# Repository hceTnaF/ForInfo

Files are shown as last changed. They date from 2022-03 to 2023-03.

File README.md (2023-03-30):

# ForInfo-V1.0 可信赖的桌面助理

## :one: 使用前准备

### 1.  硬件BOM已同步至ForInfo/1.hardware/Bom.list；
### 2.  硬件Gerber文件已同步至ForInfo/1.hardware/gerber,可直接打样（板厚1.2mm）；
### 3.  程序bin文件已同步至ForInfo/2.firmware；
### 4.  3D打印文件已同步至ForInfo/3.STL；
### 5.  ESP32程序下载工具已同步至ForInfo/5.tools；
### 6.  天气城市代码获取流程：
硬件初始化或重置后的流程中，需要在web界面填写天气城市代码以获取对应地区的天气信息，
为方便查询，可登录 [hcetnaf.com](https://www.hcetnaf.com/) 快速获取，流程如下：

#### **1）登录网站后，等待数据加载完毕；** 
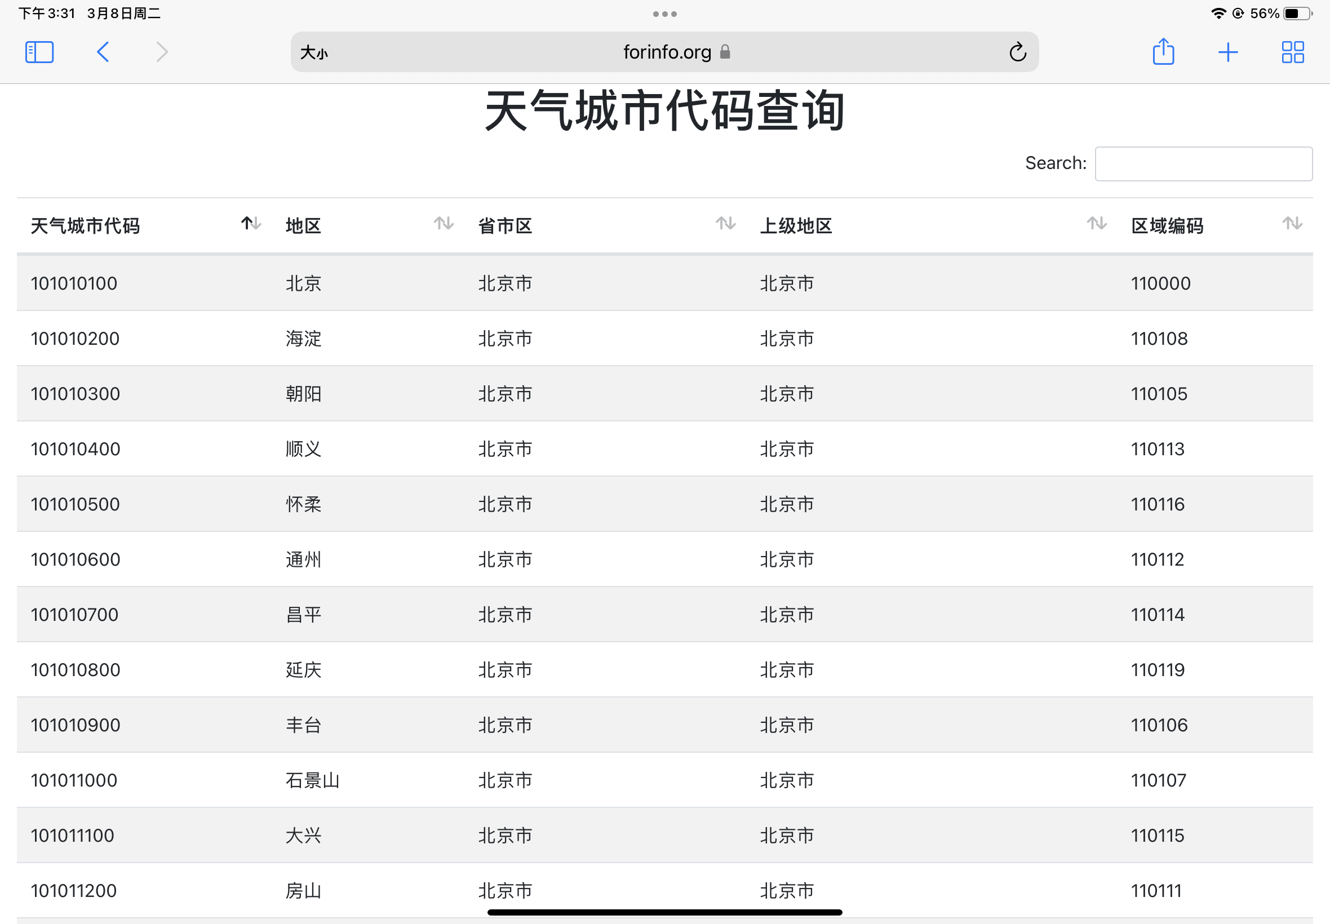
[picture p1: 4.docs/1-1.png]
数据加载

#### **2）在右上角搜索框内，可输入相应地名或区域编码完成搜索；** 
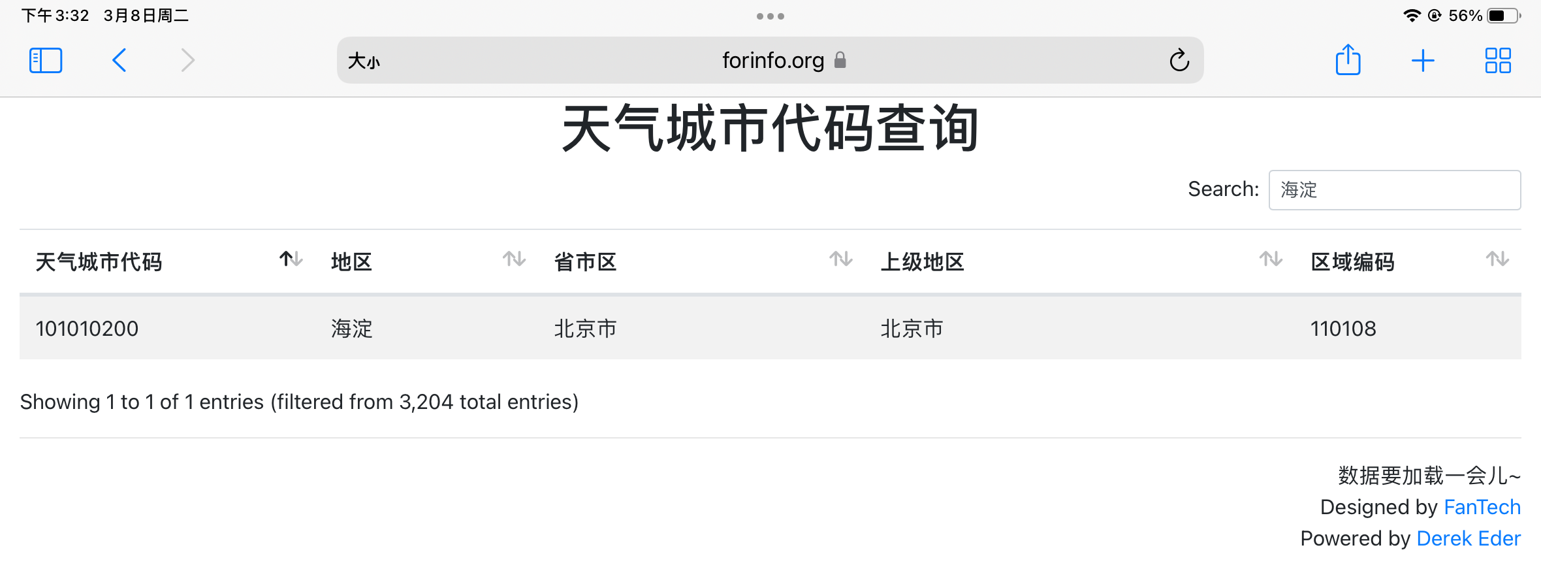
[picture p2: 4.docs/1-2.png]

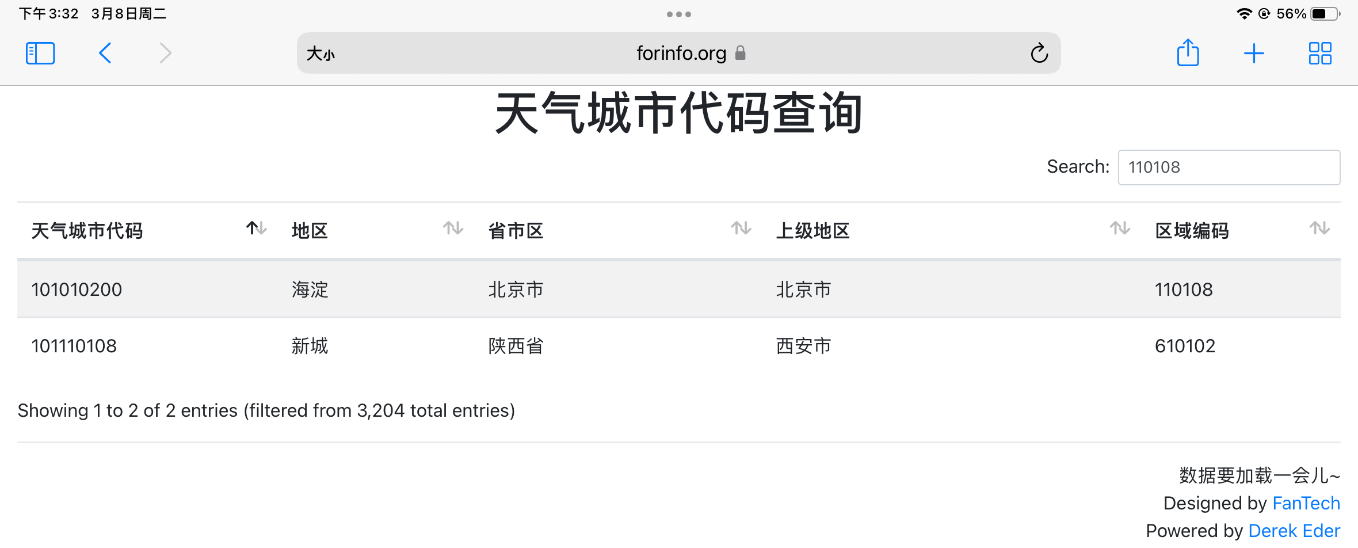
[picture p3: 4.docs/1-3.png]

#### **3）获得对应地区的天气城市代码并记录，如北京-海淀地区的天气城市代码为：101010200.** 

## :two: 下载方法
程序烧录过程，可使用 **5.tools** 中的ESP下载工具烧录，可较为方便的完成程序烧录以及后期版本升级等。双击" **flash_download_tools_v3.6.5.exe** "，选择" **ESP32 DownloadTool** ",并按照如下图所示加载4种bin文件，并正确填写后方对应的地址以及勾选下方对应的选项，如下图所示：

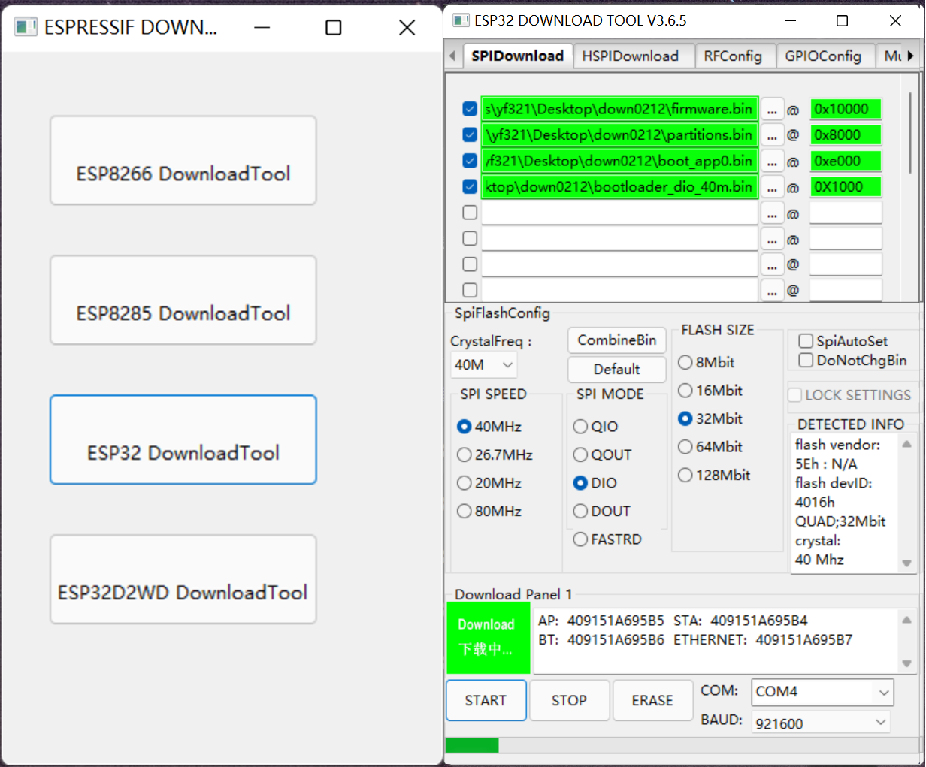
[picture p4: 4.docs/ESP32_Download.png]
下载配置


配置好相应选项后，点击 **START** 按钮方可进行下载（后续如遇异常问题，可先点击 **ERASE** 擦除后再点击 **START**）

## :three: 功能介绍

### 1.  配网过程
在系统初始化、重置系统，以及更换路由器或装置被拿到其它地方后，需要重新配置WiFi、天气城市代码、天气刷新时间、自定义字符等信息，此时装置液晶屏幕对应状态如下：

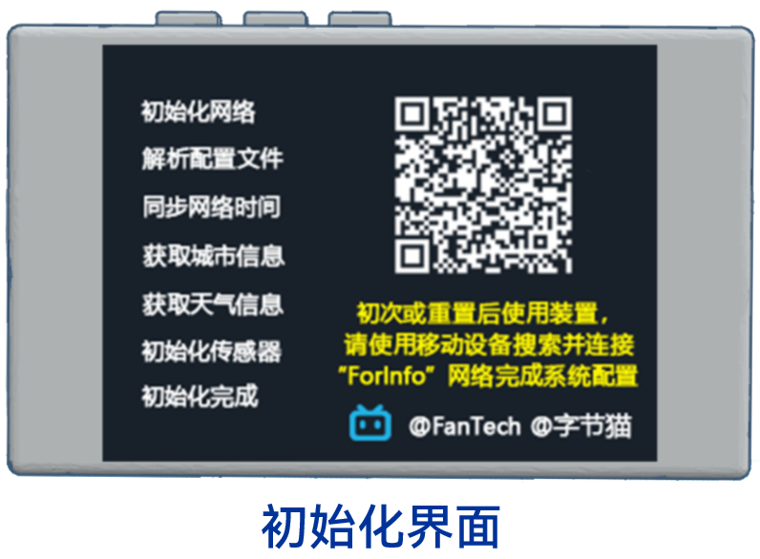
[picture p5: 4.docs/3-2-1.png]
初始化界面


其中，当出现上述几种情况时，界面会处于 **初始化界面** ，屏幕显示装置介绍二维码，可通过扫码了解装置介绍，以及获取 **天气城市代码** 等必要信息；了解了装置设置流程后，可使用移动设备搜索装置WiFi网络（ForInfo），并按照下图配置正确的信息：

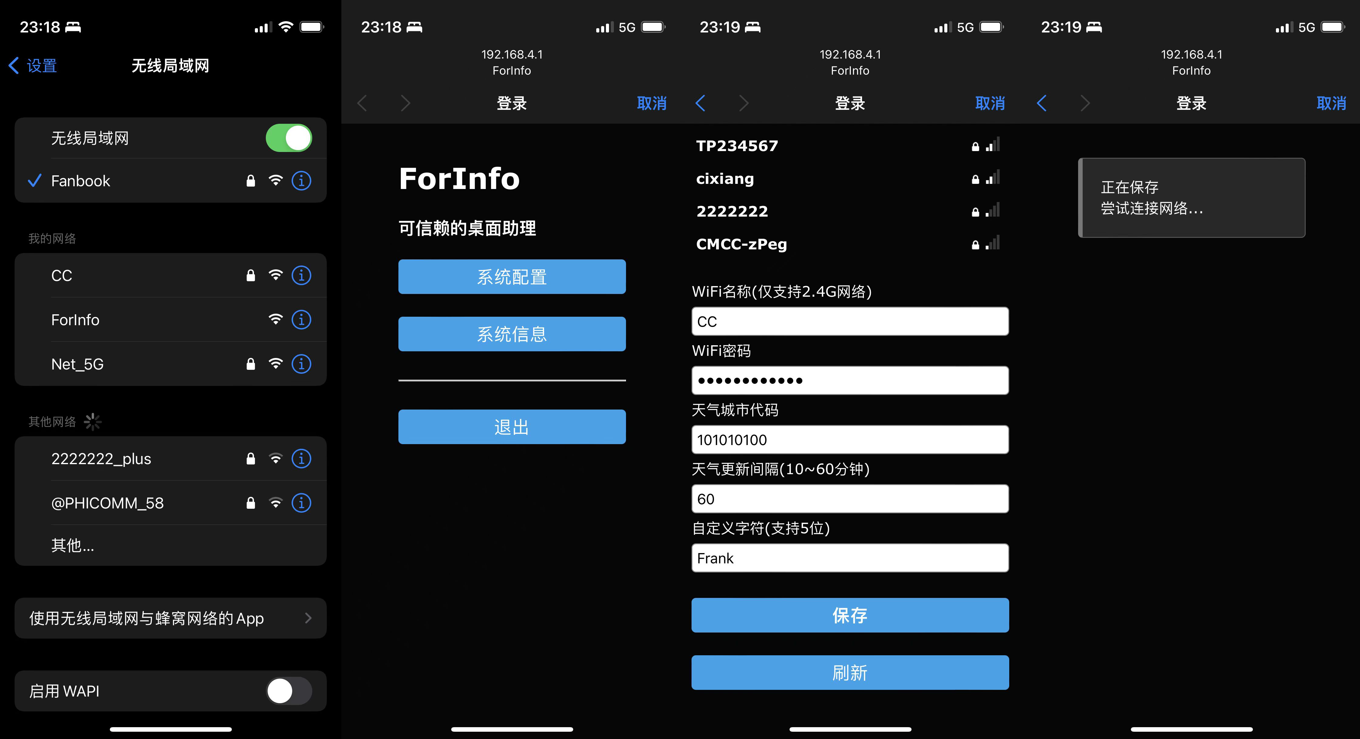
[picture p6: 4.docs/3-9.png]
配置流程


填写完成并保存后，将配置信息传输系统，等待10秒左右，液晶会处于 **配网进程** 界面，等待进度条加载完毕，可开始使用。

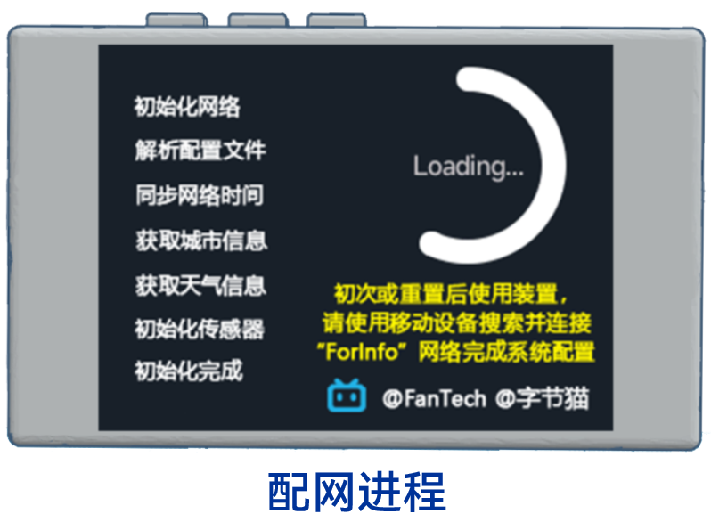
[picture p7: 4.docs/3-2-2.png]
配网进程


### 2.  功能简介
#### 1）按键功能
整体系统主要包含三个按键，分别为切换页面、屏幕亮度切换（长按重置系统）、重启，如下图所示：
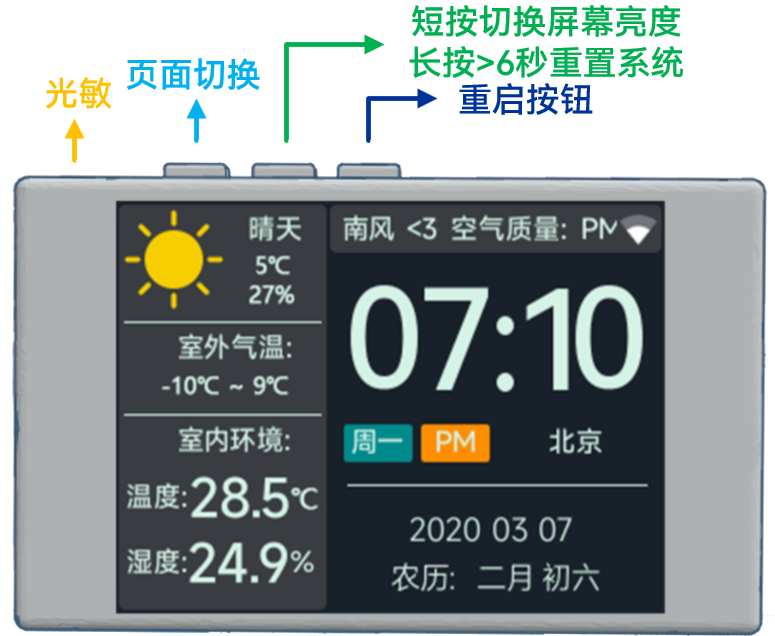
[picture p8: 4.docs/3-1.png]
按键功能

其中，最左侧为光敏电阻，用于自动调节屏幕亮度功能。
#### 2）首页 
首页中，主要包含时钟、星期、年月日、农历、当前室外天气及温湿度、室内温湿度、空气质量、风向以及WiFi信号强度，深色及浅色模式（系统根据当前时间早7-晚7为浅色模式，晚7至次日早7为深色模式，后续不再重复说明），如下所示：
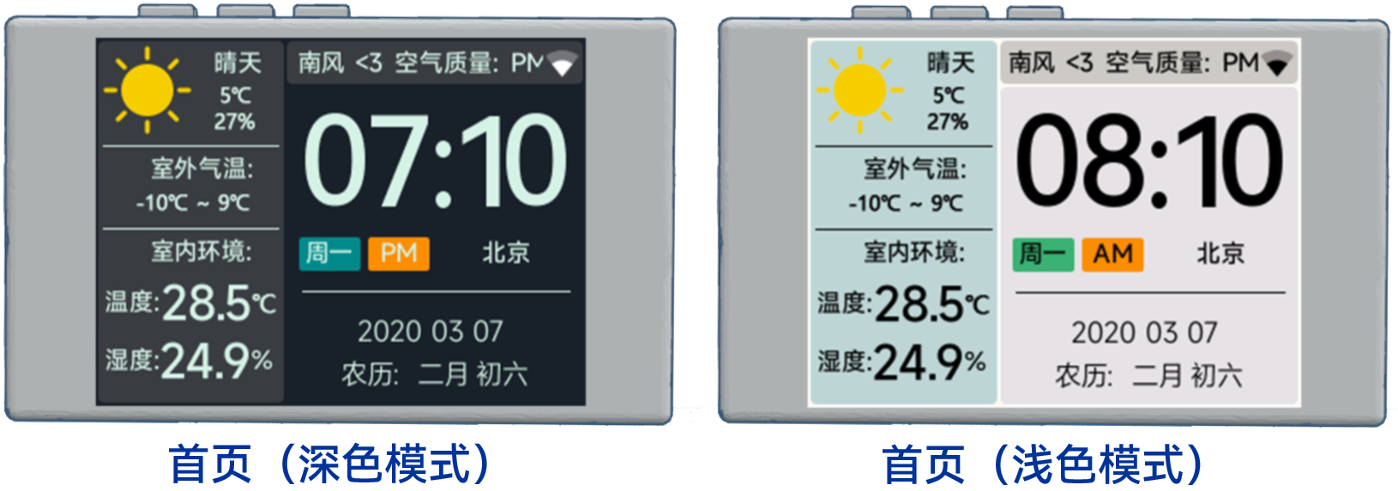
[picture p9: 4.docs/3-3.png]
首页

#### 3）关于界面
关于界面中，主要包含当前IP地址、WiFi信号强度、日期、时间、系统版本以及相关资料链接等，深色及浅色模式如下所示：
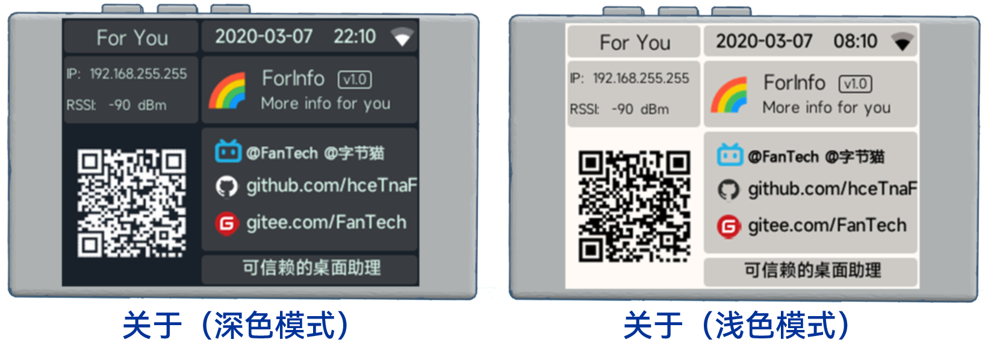
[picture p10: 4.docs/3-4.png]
关于

#### 4）简约模式
简约模式界面中，主要包含时钟、日期、星期、当前室外温度信息，如下所示：
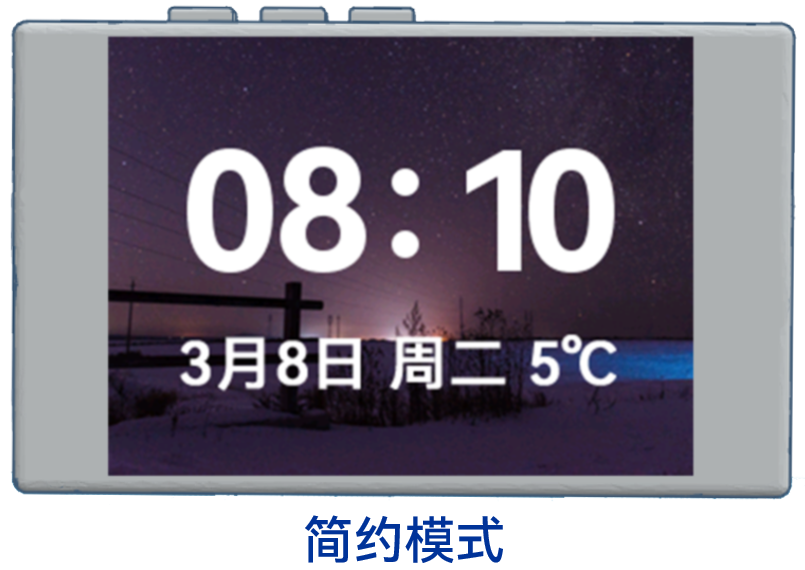
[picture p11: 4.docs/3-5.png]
简约模式

#### 5）亮度调节
装置中间的按键，单次可调节屏幕亮度，分别为：100%、70%、40、10%以及自动调节亮度，如下所示：
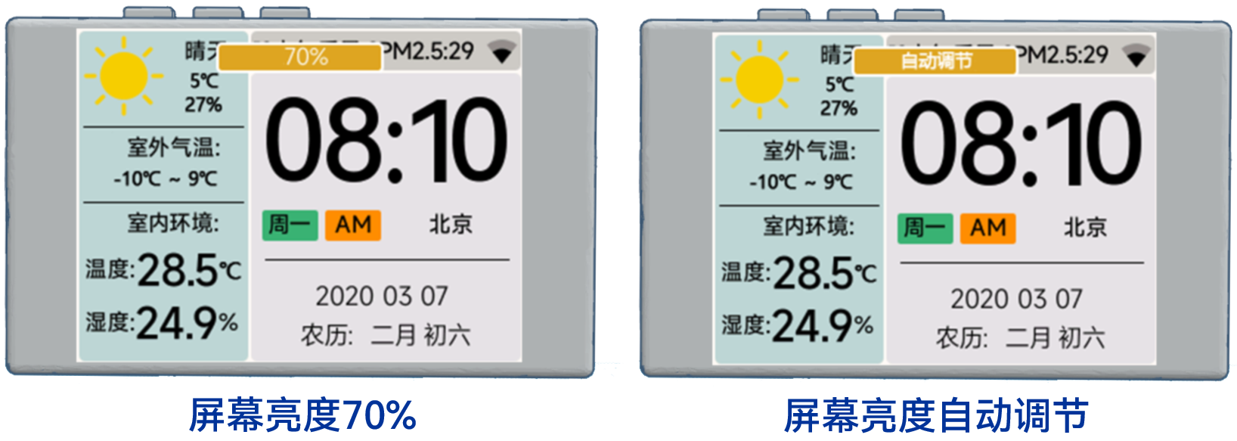
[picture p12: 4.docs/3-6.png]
亮度调节

#### 6）系统重置
装置中间的按键， **长按6秒以上** ，屏幕会出现系统开始重置的通知，后续完成系统初始化的操作，如下所示：
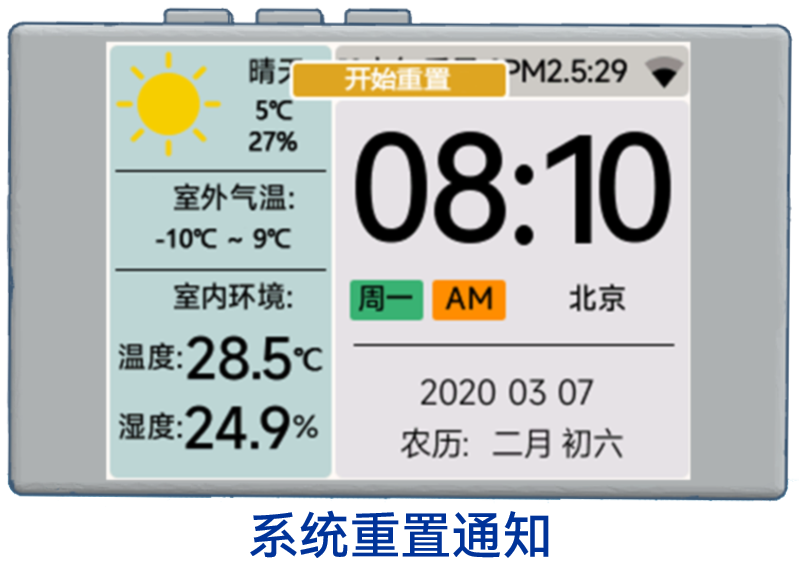
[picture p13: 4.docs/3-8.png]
系统重置

#### 7）版本更新
在关于界面系统版本位置，当检测到系统有更新时，会在版本后显示"new"提示，用户便可以通过下载资料库中最新的bin文件，完成更新下载，如下所示：
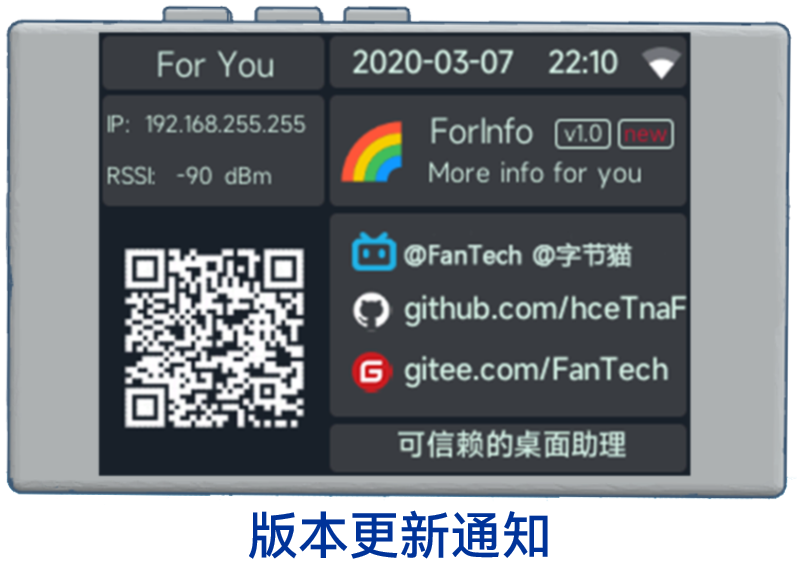
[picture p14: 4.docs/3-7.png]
版本更新

**后续会对固件不断优化更新，请关注B站动态！**

## :four: 注意事项
### 1.  焊接注意
1）光敏电阻距离电路板2mm左右；

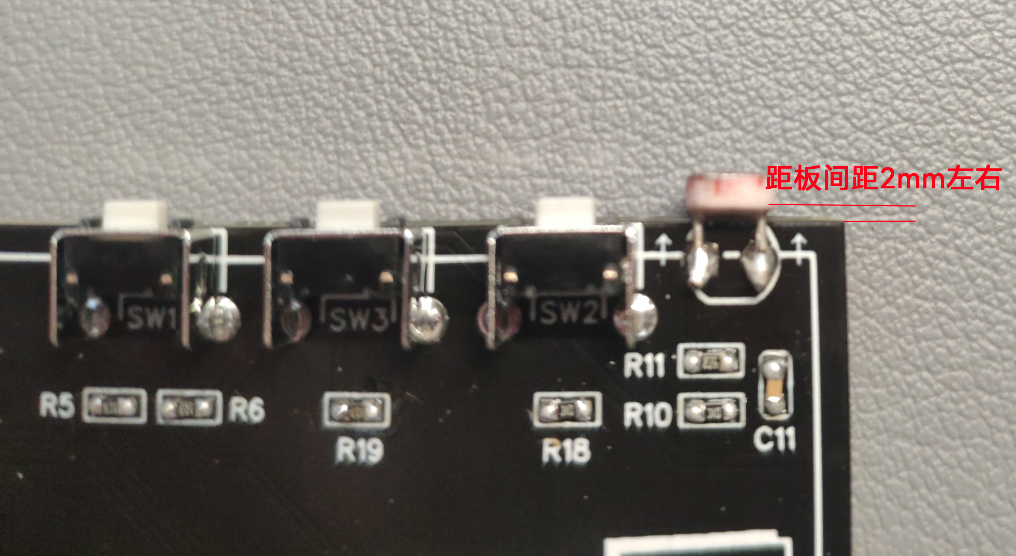
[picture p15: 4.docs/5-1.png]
引脚长度


2）注意如CH340C、SHTC3、电源LED（3V3）、二极管的元器件焊接方向；

3）手工焊接先检查电源，再通电开机；

### 2.  装配注意
屏幕左右两侧螺丝为 **M1.6长度4mm** 共2个；底座小板固定及盖板固定为 **M1.6长度5mm** 共8个；
### 3.  使用注意
1）温湿度传感器由于周围板子温度、环境温度干扰与实际室温不相符合，数据仅供参考；

2）根据3D打印材料不同，尽可能避免在高湿高温环境中长时间使用；

3）type-C数据线用于对装置的供电以及程序下载，尽可能选择带有数据功能5V1A以上线材，电源适配器供电电流≥1A；

4）部分使用WEB Portal方式的校园网络无法使用，建议在路由器的WiFi网络环境下使用；

5）该作品仅限用户个人DIY， **禁止个人私自产品化** ，如有问题请在B站私信联系[@FanTech](https://space.bilibili.com/12102785).

## :five: 关于

### 1.  主要贡献：@[FanTech](https://space.bilibili.com/12102785) @[字节猫](https://space.bilibili.com/177322563) 微信公众号：ForInfo
### 2.  壁纸拍摄：(龙镇夜空) @[远山淡影x ](https://space.bilibili.com/378962375)
### 3.  感谢@[Derek Eder](https://github.com/derekeder/csv-to-html-table),[forinfo.org](https://www.forinfo.org)查询网页基于 **Derek Eder** 修改
### 4.  感谢@[tzapu](https://github.com/tzapu/WiFiManager),wifi配置界面基于 **tzapu** 作者汉化及修改
### 5.  项目开发基于[乐鑫ESP32](https://github.com/espressif/arduino-esp32)及[LVGL开源框架](https://github.com/lvgl/lvgl)支持
### 6.  装配视频在bilibili：@[FanTech](https://space.bilibili.com/12102785)
### 7.  gitee地址：[https://gitee.com/FanTech](https://gitee.com/FanTech)

欢迎star :)

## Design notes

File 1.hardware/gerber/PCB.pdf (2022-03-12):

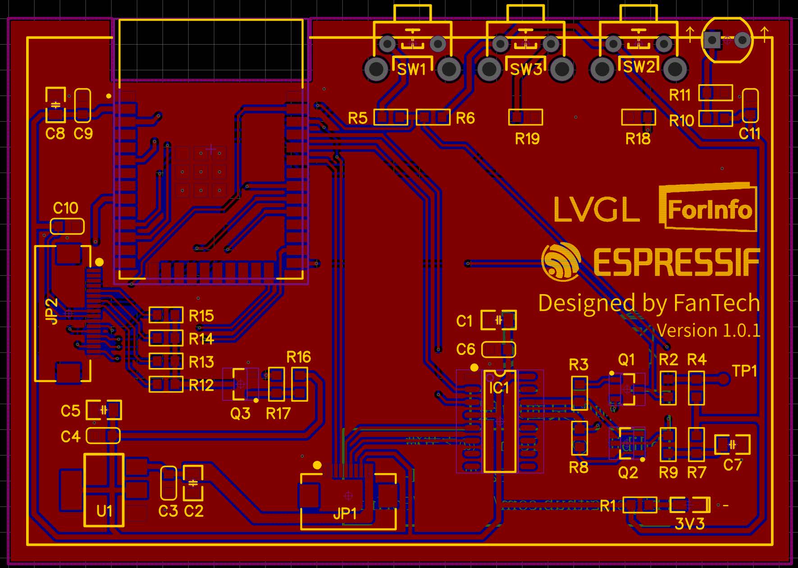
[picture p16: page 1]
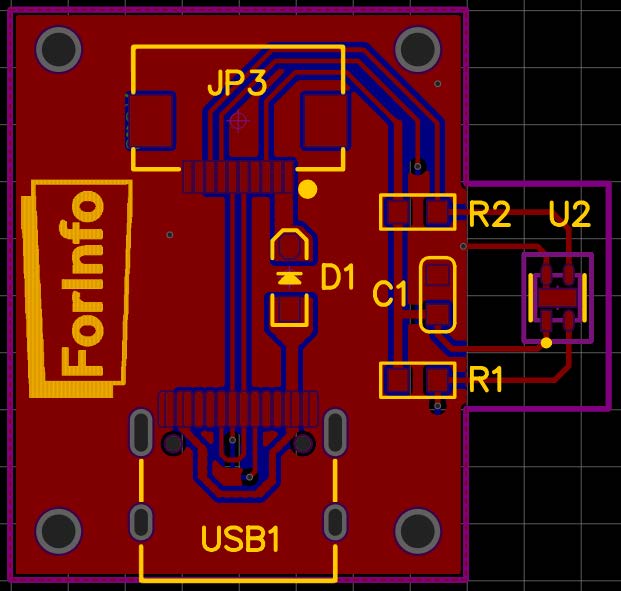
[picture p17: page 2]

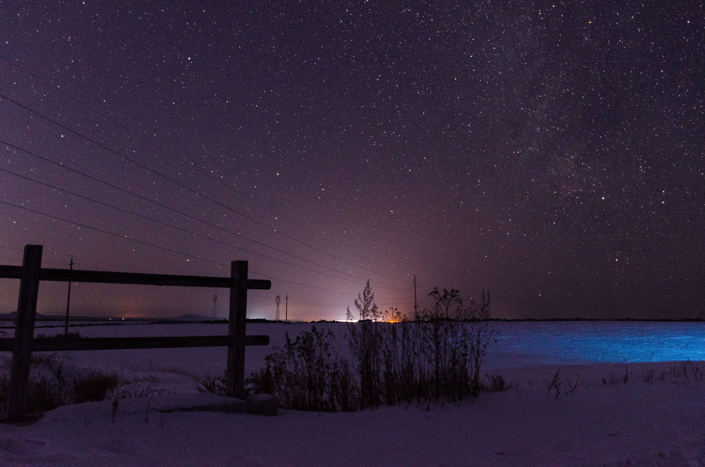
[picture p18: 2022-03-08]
4.docs/wallpaper.jpg

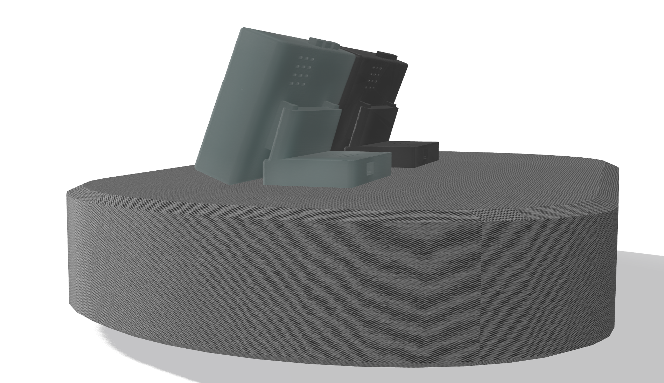
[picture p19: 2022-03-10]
4.docs/ForInfo_2.png

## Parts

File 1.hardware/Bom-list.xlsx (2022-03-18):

种类 | 名称 | 封装(厂家) | 数量 | 备注 | 位号 | 链接
主控 | ESP32-WROOM-32 | 乐鑫 模组 | 1 | 4MB |  | https://item.taobao.com/item.htm?spm=a1z10.5-c-s.w4002-22443450244.13.30394544TGsvwN&id=543558533446
液晶屏幕 | 3.2寸 LCD显示屏 | 中景园 ST7789驱动 无触摸 | 1 | ST7789 |  | https://item.taobao.com/item.htm?spm=a1z09.2.0.0.15b92e8dvgrfaL&id=610228995267&_u=9mqscbj1e01
传感器 | 温湿度传感器 | SHTC3 DFN-4 | 1 |  | U2(TYPE-C板) | https://item.taobao.com/item.htm?id=602285152762&ns=1&abbucket=14 (https://item.taobao.com/item.htm?spm=a230r.1.14.16.173a64a49so6nk&id=602285152762&ns=1&abbucket=14)
 | 光敏电阻 | 5528 直插 | 1 |  |  | https://item.taobao.com/item.htm?spm=a1z09.2.0.0.15b92e8dvgrfaL&id=522556415238&_u=9mqscbj69e0
芯片 | USB转串口芯片 | CH340C SOP-16 | 1 |  | IC1 | https://item.taobao.com/item.htm?spm=a1z10.3-c-s.w4002-21223910208.9.5bfc6a4b206nNj&id=572355836370
 | 线性稳压LDO | AMS1117-3.3V SOT-223 | 1 |  | U1 | https://item.taobao.com/item.htm?spm=a1z10.3-c-s.w4002-21223910208.10.1c946a4bXc70V3&id=522572478170
电阻 | 39R | 0603 | 4 |  | R12, R13, R14, R15 | https://item.taobao.com/item.htm?spm=a1z10.3-c-s.w4002-21223910208.28.4bba6a4bOl9yLE&id=525753060864
 | 12k |  | 1 |  | R6 | https://item.taobao.com/item.htm?spm=a1z10.3-c-s.w4002-21223910208.12.53f36a4bSdH9Ot&id=525832832541
 | 10k |  | 13 |  | R1, R2, R3, R4, R7, R8, R9, R10, R16, R18, R19,R1(TYPE-C板),R2(TYPE-C板) | https://item.taobao.com/item.htm?spm=a1z10.3-c-s.w4002-21223910208.28.37496a4bXLjvpH&id=525777943950
 | 1k |  | 1 |  | R17 | https://item.taobao.com/item.htm?spm=a1z10.3-c-s.w4002-21223910208.24.1f586a4bWooCVS&id=525795113143
 | 470R |  | 1 |  | R5 | https://item.taobao.com/item.htm?spm=a1z10.3-c-s.w4002-21223910208.10.23a66a4bGYz8YZ&id=525787826203
 | 4.7k |  | 1 |  | R11 | https://item.taobao.com/item.htm?spm=a1z10.3-c-s.w4002-21223910208.14.22826a4bAISjus&id=525820369368
电容 | 10uF | 0805 25V ±10% | 5 |  | C1, C2, C5, C7, C8 | https://item.taobao.com/item.htm?spm=a1z10.3-c-s.w4002-21223910208.10.49a66a4bfLl33V&id=537816489806
 | 0.1uF | 0603 50V ±10% | 7 |  | C3, C4, C6, C9, C10, C11,C1(TYPE-C板) | https://item.taobao.com/item.htm?spm=a1z10.3-c-s.w4002-21223910208.9.231f6a4b5hG4JE&id=522573286298
二极管 | 发光二极管 | 0603 | 1 |  | 3V3 | https://item.taobao.com/item.htm?spm=a1z10.3-c-s.w4002-21223910208.28.22ce6a4bkXKcVY&id=522573349430
 | 1N5819 | SOD-323 | 1 |  | D1(TYPE-C板) | https://item.taobao.com/item.htm?spm=a1z09.2.0.0.7ce92e8dShKsgv&id=522574162326&_u=gmqscbj0255
三极管 | S8050 | J3Y SOT-23 | 3 |  | Q1, Q2, Q3 | https://item.taobao.com/item.htm?spm=a1z10.3-c-s.w4002-21223910208.9.31716a4bAnVZq8&id=522577964105
排线 | FPC软排线 | 10P 0.5mm 同向 6cm | 1 |  |  | https://item.taobao.com/item.htm?spm=a1z09.2.0.0.194c2e8dhw5Ch0&id=549591782090&_u=imqscbjd960
数据线 | Type-C数据线 | ZMI紫米 | 1 | 任选 1A以上即可 |  | https://detail.tmall.com/item.htm?id=529091830072&ns=1&abbucket=8&skuId=4886858450788
接插件 | TYPE-C母座 | 16P | 1 |  | USB1 | https://item.taobao.com/item.htm?spm=a1z10.3-c-s.w4002-21223910208.12.7f4f6a4biuqfNM&id=573090887123
 | FPC连接器0.5MM | 下接 10P | 2 |  | JP1,JP3(TYPE-C板) | https://item.taobao.com/item.htm?spm=a1z09.2.0.0.89062e8doi41I6&id=552629356951&_u=6mqscbj254c
 | FPC连接器0.5MM | 下接 18P | 1 |  | JP2 | https://item.taobao.com/item.htm?spm=a1z09.2.0.0.15b92e8dvgrfaL&id=552629356951&_u=9mqscbj3a89
 | 微动开关 | 3*6*5MM 立式 | 3 |  | SW1, SW2, SW3 | https://item.taobao.com/item.htm?spm=a1z09.2.0.0.15b92e8dvgrfaL&id=522575322631&_u=9mqscbjd526
 | 沉头十字平尾自攻螺丝 | M1.6*4 | 2 | 液晶壳体左右两侧
 | 沉头十字平尾自攻螺丝 | M1.6*5 | 8 | 底座固定

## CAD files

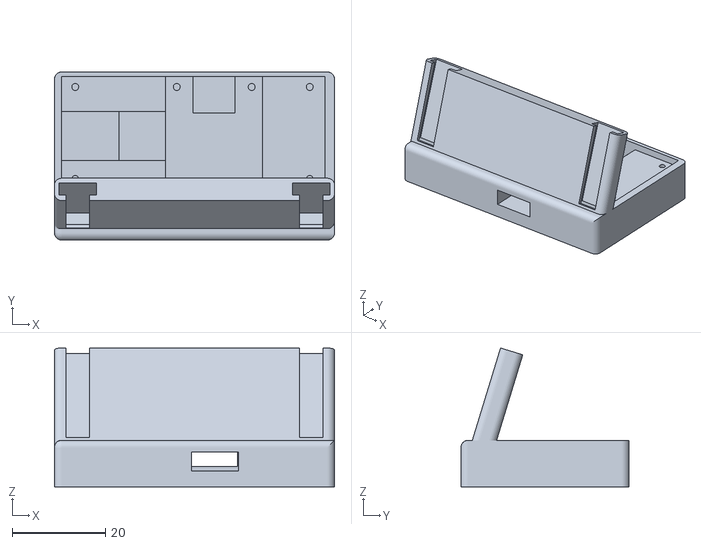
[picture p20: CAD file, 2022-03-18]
3.stl/1-5.stl
60.0 x 36.0 x 29.8

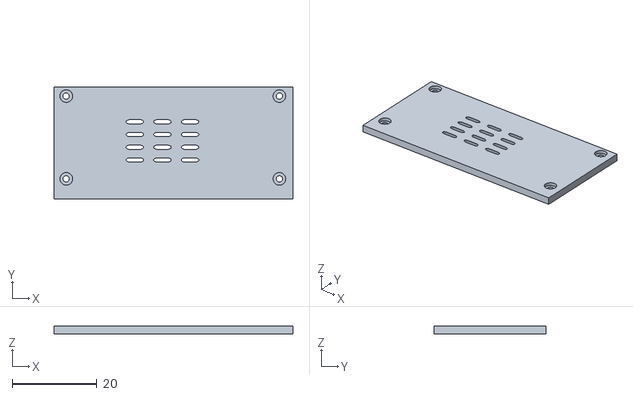
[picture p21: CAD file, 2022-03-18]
3.stl/4-5.stl
56.3 x 26.5 x 1.80

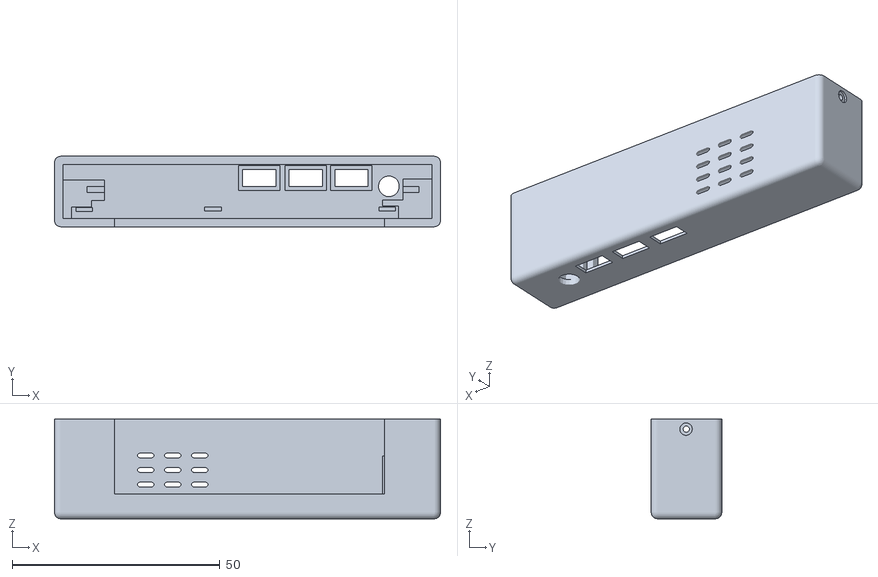
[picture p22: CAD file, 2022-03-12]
3.stl/3-5.stl
93.0 x 17.0 x 24.0

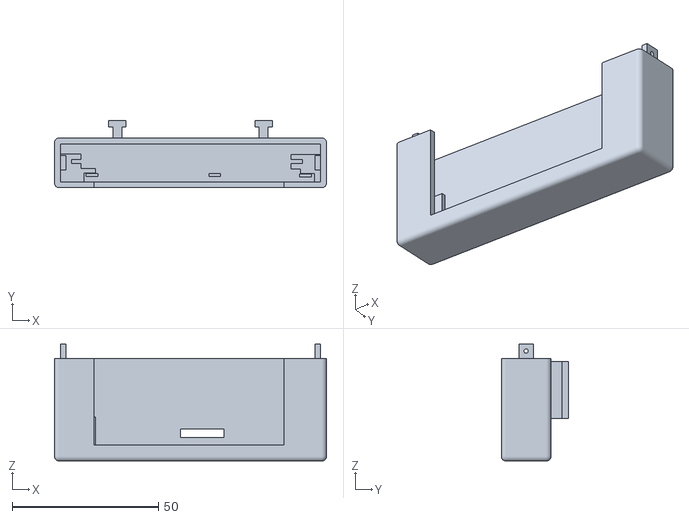
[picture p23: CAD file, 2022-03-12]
3.stl/2-5.stl
93.0 x 23.0 x 40.0

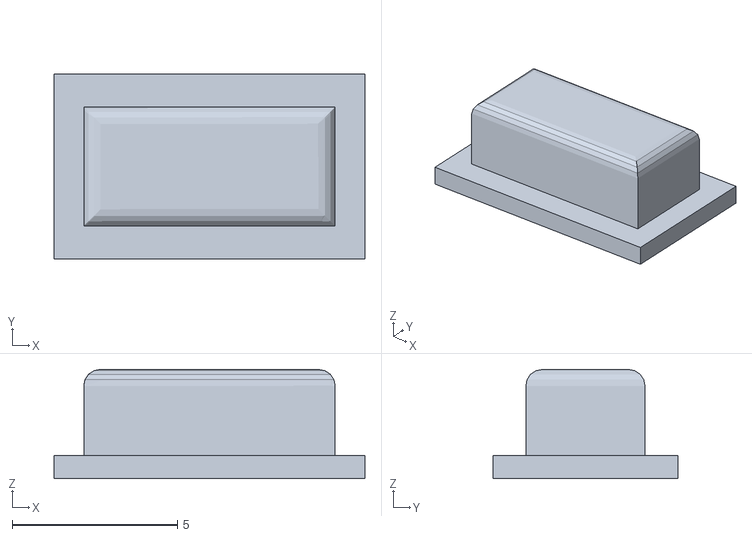
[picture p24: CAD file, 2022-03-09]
3.stl/5-5（共3个）.stl
9.40 x 5.60 x 3.30
